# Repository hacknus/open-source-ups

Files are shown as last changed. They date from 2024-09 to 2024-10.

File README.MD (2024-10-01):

# Open Source UPS
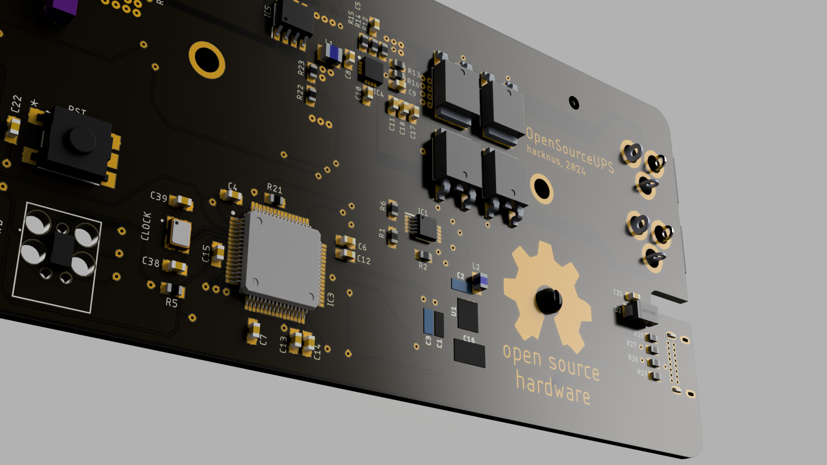
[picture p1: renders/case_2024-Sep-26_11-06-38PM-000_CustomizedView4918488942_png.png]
pcb view


UPS are commonly used in server applications to protect against power outages. For home applications, for example to protect a NAS, small Uninterruptible Power Supplies (UPS) do exist, but they all lack the USB HID communication to shut down the NAS/Server/Host when the battery gets low.
For small scale applications like Synology NAS products that operate at 12V, there currently exists no UPS product that is able to buffer the power and communicate over USB when the battery level gets critically low.
Only high voltage solutions (110V or 230V) exist, which also include an inverter and are thus much less efficient and overpowered for a simple 12V Synology NAS.
This is a simple, open source UPS, based around an STM32F405 and written in Rust.

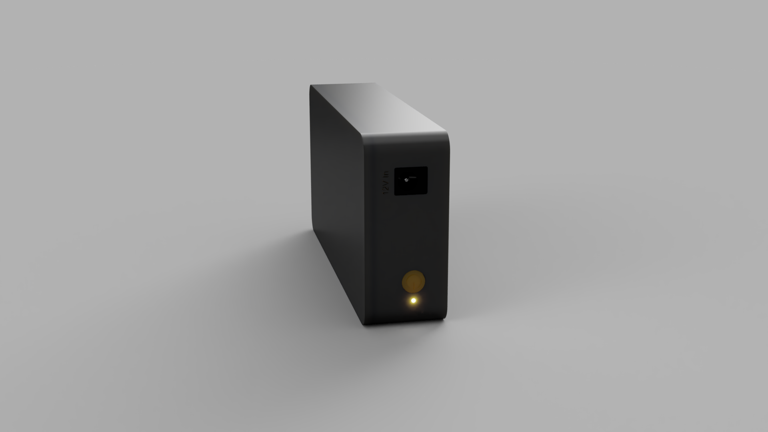
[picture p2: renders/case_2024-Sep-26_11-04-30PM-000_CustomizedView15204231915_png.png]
front view

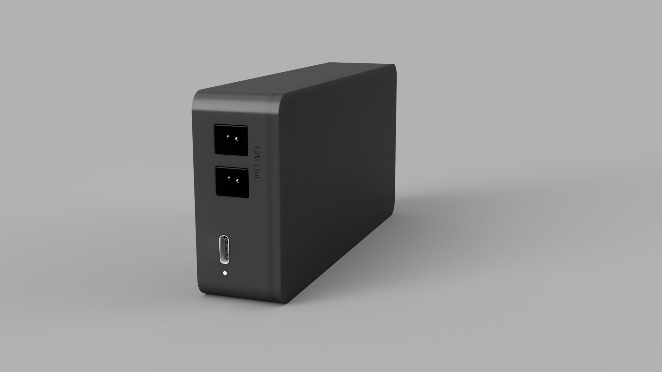
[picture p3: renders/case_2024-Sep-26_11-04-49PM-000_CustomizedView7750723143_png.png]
back view

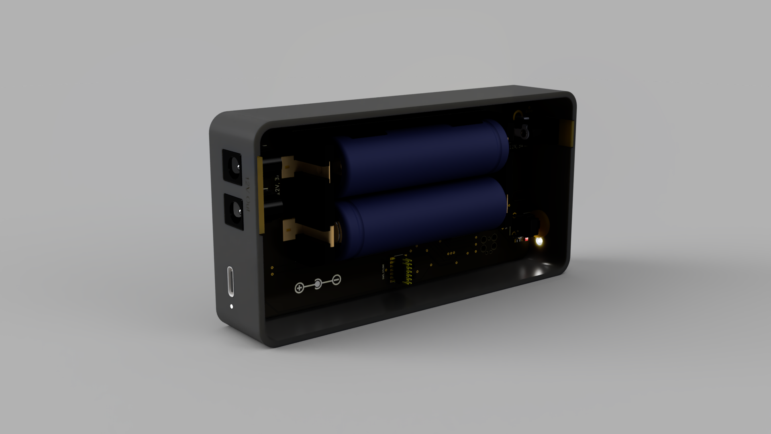
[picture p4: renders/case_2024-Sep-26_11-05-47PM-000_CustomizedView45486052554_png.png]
inside view


The USB HID communication is based on the great work done by [abratchik](https://github.com/abratchik) for the Arduino platform [here](https://github.com/abratchik/HIDPowerDevice/tree/master). 
The hardware is essentially just a charging circuit where the remaining capacity is monitored by the MCU.

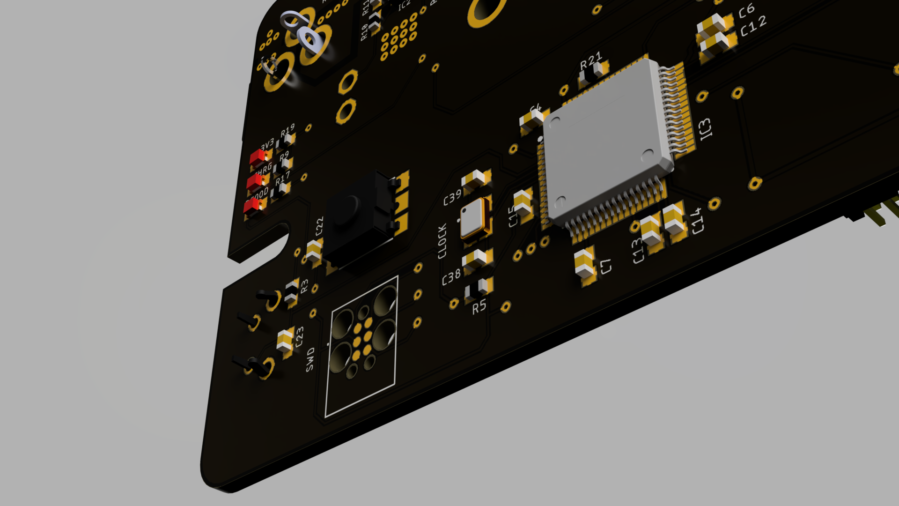
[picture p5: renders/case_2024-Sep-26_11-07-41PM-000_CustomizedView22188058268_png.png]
pcb view


## Hardware
Attention! This pcb does not contain a battery protection circuit - if you wish to implement one, just use the Keystone 1047 battery case instead of the Keystone 1048P and wire a breakout 2S BMS before connecting the batteries to the PCB.
The hardware can be found in the [hardware folder](hardware), containing step files for the case as well as EAGLE files for the PCB.

## Flashing the firmware
Connect the board using a ST-Link V3 (with TagConnect) to a USB port on the computer. Be sure to power the board with an
additional USB-C connector. (ST-Link does not provide power)  
First start the openocd server in a terminal/console window:
```openocd -f interface/stlink-v2-1.cfg -f target/stm32f4x.cfg```   
Flash/Run the code on the hardware using:  
```cargo run --release```  
note: release is important for USB to work reliably!

To set up your system, be sure to
follow [this guide](https://docs.rust-embedded.org/discovery/f3discovery/03-setup/index.html)!

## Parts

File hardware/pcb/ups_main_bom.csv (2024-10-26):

Qty | Value | Device | Package | Parts | Description | ARROW_PART_NUMBER | ARROW_PRICE-STOCK | AVAILABILITY | BUILT_BY | CONFIGURATION__POLE-THROW_ | COPYRIGHT | DESCRIPTION | HEIGHT | MANUFACTURER_NAME | MANUFACTURER_PART_NUMBER | MAX_SWITCHING_CURRENT | MAX_SWITCHING_VOLTAGE_AC_ | MF | MOUSER_PART_NUMBER | MOUSER_PRICE-STOCK | MP | PACKAGE | POPULARITY | PRICE | PRODUCT_TYPE | PROD_ID | PURCHASE-URL | RS_PART_NUMBER | RS_PRICE-STOCK | SPICEPREFIX | SWITCH_TYPE | TE_PART_NUMBER | TP_SIGNAL_NAME | VALUE | VENDOR
5 |  | LEDCHIPLED_0805 | CHIPLED_0805 | 3V3, CHRG, FLT, PGOOD, STAT | LED
1 | 0.1uF | 0.1UF-0603-25V-5% | 603 | C2 | 0.1µF ceramic capacitors |  |  |  |  |  |  |  |  |  |  |  |  |  |  |  |  |  |  |  |  | CAP-08604 |  |  |  |  |  |  |  | 0.1uF
9 | 0.1uF | C-EUC0603K | C0603K | C4, C6, C7, C14, C15, C19, C20, C22, C23 | CAPACITOR, European symbol |  |  |  |  |  |  |  |  |  |  |  |  |  |  |  |  |  | 30 |  |  |  |  |  |  | C
1 | 1-1571636-0 | 1-1571636-0 | SW5_1571636 | RST |  |  |  |  | EMA_UL_Team | Single Pole - Single Throw | Copyright (C) 2016 Accelerated Designs. All rights reserved | TACT,SMT,GULL WING,260GF,T&R |  |  | 1-1571636-0 | - | - |  |  |  |  |  |  |  | Switch |  |  |  |  |  | Tactile Switches | 1-1571636-0 |  |  | TE Connectivity
1 | 1.21k | R-EU_R0603 | R0603 | R11 | RESISTOR, European symbol |  |  |  |  |  |  |  |  |  |  |  |  |  |  |  |  |  | 70 |  |  |  |  |  |  | R
1 | 1.54M | R-EU_R0603 | R0603 | R7 | RESISTOR, European symbol |  |  |  |  |  |  |  |  |  |  |  |  |  |  |  |  |  | 70 |  |  |  |  |  |  | R
1 | 1.5uF | C-EUC0603K | C0603K | C9 | CAPACITOR, European symbol |  |  |  |  |  |  |  |  |  |  |  |  |  |  |  |  |  | 30 |  |  |  |  |  |  | C
1 | 1000pF | C-EUC0603K | C0603K | C5 | CAPACITOR, European symbol |  |  |  |  |  |  |  |  |  |  |  |  |  |  |  |  |  | 30 |  |  |  |  |  |  | C
1 | 100nF | C-EUC0603K | C0603K | C8 | CAPACITOR, European symbol |  |  |  |  |  |  |  |  |  |  |  |  |  |  |  |  |  | 30 |  |  |  |  |  |  | C
1 | 1048P | 1048P | 1048P | U2 | KEYSTONE - 1048P - BATTERY HOLDER, 18650, SMD |  |  |  |  |  |  | KEYSTONE - 1048P - BATTERY HOLDER, 18650, SMD | mm | Keystone Electronics | 1048P |  |  |  | 534-1048P | https://www.mouser.co.uk/ProductDetail/Keystone-Electronics/1048P?qs=9%252Bwcgl%2FJqd1h8Vx3IFpTxA%3D%3D
4 | 10k | R-EU_R0603 | R0603 | R3, R5, R10, R21 | RESISTOR, European symbol |  |  |  |  |  |  |  |  |  |  |  |  |  |  |  |  |  | 70 |  |  |  |  |  |  | R
1 | 10uF | 10UF-1210-50V-20% | 1210 | C16 | 10.0µF ceramic capacitors |  |  |  |  |  |  |  |  |  |  |  |  |  |  |  |  |  |  |  |  | CAP-09824 |  |  |  |  |  |  |  | 10uF
4 | 10uF | C-EUC0603K | C0603K | C12, C13, C17, C18 | CAPACITOR, European symbol |  |  |  |  |  |  |  |  |  |  |  |  |  |  |  |  |  | 30 |  |  |  |  |  |  | C
1 | 158k | R-EU_R0603 | R0603 | R2 | RESISTOR, European symbol |  |  |  |  |  |  |  |  |  |  |  |  |  |  |  |  |  | 70 |  |  |  |  |  |  | R
1 | 18k | R-EU_R0603 | R0603 | R15 | RESISTOR, European symbol |  |  |  |  |  |  |  |  |  |  |  |  |  |  |  |  |  | 70 |  |  |  |  |  |  | R
5 | 1k | R-EU_R0603 | R0603 | R9, R17, R18, R19, R31 | RESISTOR, European symbol |  |  |  |  |  |  |  |  |  |  |  |  |  |  |  |  |  | 70 |  |  |  |  |  |  | R
3 | 1uF | C-EUC0603K | C0603K | C11, C21, C25 | CAPACITOR, European symbol |  |  |  |  |  |  |  |  |  |  |  |  |  |  |  |  |  | 30 |  |  |  |  |  |  | C
1 | 2.2uF | C-EUC0603K | C0603K | C10 | CAPACITOR, European symbol |  |  |  |  |  |  |  |  |  |  |  |  |  |  |  |  |  | 30 |  |  |  |  |  |  | C
1 | 200k | R-EU_R0603 | R0603 | R6 | RESISTOR, European symbol |  |  |  |  |  |  |  |  |  |  |  |  |  |  |  |  |  | 70 |  |  |  |  |  |  | R
3 | 20k | R-EU_R0603 | R0603 | R1, R13, R16 | RESISTOR, European symbol |  |  |  |  |  |  |  |  |  |  |  |  |  |  |  |  |  | 70 |  |  |  |  |  |  | R
2 | 22 | R-EU_R0603 | R0603 | R26, R27 | RESISTOR, European symbol |  |  |  |  |  |  |  |  |  |  |  |  |  |  |  |  |  | 70 |  |  |  |  |  |  | R
2 | 22pF | C-EUC0603K | C0603K | C38, C39 | CAPACITOR, European symbol |  |  |  |  |  |  |  |  |  |  |  |  |  |  |  |  |  | 30 |  |  |  |  |  |  | C
2 | 22uF | 22UF-0603-6.3V-20% | 603 | C1, C3 | 22µF ceramic capacitors |  |  |  |  |  |  |  |  |  |  |  |  |  |  |  |  |  |  |  |  | CAP-14464 |  |  |  |  |  |  |  | 22uF
1 | 22uF | C-EUC0603K | C0603K | C26 | CAPACITOR, European symbol |  |  |  |  |  |  |  |  |  |  |  |  |  |  |  |  |  | 30 |  |  |  |  |  |  | C
1 | 249k | R-EU_R0603 | R0603 | R8 | RESISTOR, European symbol |  |  |  |  |  |  |  |  |  |  |  |  |  |  |  |  |  | 70 |  |  |  |  |  |  | R
2 | 27k | R-EU_R0603 | R0603 | R22, R25 | RESISTOR, European symbol |  |  |  |  |  |  |  |  |  |  |  |  |  |  |  |  |  | 70 |  |  |  |  |  |  | R
1 | 280k | R-EU_R0603 | R0603 | R12 | RESISTOR, European symbol |  |  |  |  |  |  |  |  |  |  |  |  |  |  |  |  |  | 70 |  |  |  |  |  |  | R
2 | 4k7 | R-EU_R0603 | R0603 | R28, R29 | RESISTOR, European symbol |  |  |  |  |  |  |  |  |  |  |  |  |  |  |  |  |  | 70 |  |  |  |  |  |  | R
2 | 68k | R-EU_R0603 | R0603 | R23, R24 | RESISTOR, European symbol |  |  |  |  |  |  |  |  |  |  |  |  |  |  |  |  |  | 70 |  |  |  |  |  |  | R
3 | 694106301002 | 694106301002 | 694106301002_1 | J1, J2, J3 | WURTH ELEKTRONIK - 694106301002 - CONNECTOR, POWER ENTRY, JACK, 3A, 20VDC |  |  |  |  |  |  | WURTH ELEKTRONIK - 694106301002 - CONNECTOR, POWER ENTRY, JACK, 3A, 20VDC | mm | Wurth Elektronik | 694106301002 |  |  |  | 710-694106301002 | https://www.mouser.co.uk/ProductDetail/Wurth-Elektronik/694106301002?qs=a9WhcLg8qCwOEkcI62k5mA%3D%3D
1 | 80.6k | R-EU_R0603 | R0603 | R14 | RESISTOR, European symbol |  |  |  |  |  |  |  |  |  |  |  |  |  |  |  |  |  | 70 |  |  |  |  |  |  | R
1 | 8MHz | ABM8AIG-8.000MHZ-1Z-T | ABM8AIG8000MHZ1ZT | CLOCK | Crystals 18pF 8MHz 10ppm AEC-Q200 -40C +125C |  |  |  |  |  |  | Crystals 18pF 8MHz 10ppm AEC-Q200 -40C +125C | 0.8mm | ABRACON | ABM8AIG-8.000MHZ-1Z-T |  |  |  | 815-M8AIG-8-1ZT | https://www.mouser.com/Search/Refine.aspx?Keyword=815-M8AIG-8-1ZT
1 | AP63203 | AP63203 | SOT23-6 | U1 | Diodes Inc. AP63203 3.8V-32V input 3.3V Buck |  |  |  |  |  |  |  |  |  |  |  |  |  |  |  |  |  |  |  |  | VREG-15244 |  |  |  |  |  |  |  | AP63203
1 | FSMRACDAH | FSMRACDAH | FSMRACDAH | SW | TE CONNECTIVITY / ALCOSWITCH - FSMRACDAH - TACTILE SWITCH, SPST-NO, 0.05A, 24V, TH |  |  |  |  |  |  | TE CONNECTIVITY / ALCOSWITCH - FSMRACDAH - TACTILE SWITCH, SPST-NO, 0.05A, 24V, TH | 9.2mm | TE Connectivity | FSMRACDAH |  |  |  | 506-FSMRACDAH | https://www.mouser.co.uk/ProductDetail/TE-Connectivity-Alcoswitch/FSMRACDAH?qs=GXuM9q1TrDlqFSLkwG2zzQ%3D%3D
1 | FTSH-107-01-L-DV-K | FTSH-107-01-L-DV-K | FTSH-107-XX-YYY-DV-K | SWD_STLINK | 14 Position, High Reliability Header Strips, 0.050 pitch" | FTSH-107-01-L-DV-K | https://www.arrow.com/en/products/ftsh-107-01-l-dv-k/samtec |  |  |  |  | 14 Position, High Reliability Header Strips, 0.050&quot | pitch | mm | SAMTEC | FTSH-107-01-L-DV-K |  |  |  | 200-FTSH10701LDVK | https://www.mouser.co.uk/ProductDetail/Samtec/FTSH-107-01-L-DV-K?qs=%252BZP6%2F%252BtExtBNGLAeWROTVA%3D%3D
4 | IPD068P03L3GATMA1 | IPD068P03L3GATMA1 | IPD068P03L3GATMA1 | Q1, Q2, Q3, Q4 | MOSFET TRENCH |  |  |  |  |  |  | MOSFET TRENCH <= 40V | 2.41mm | Infineon | IPD068P03L3GATMA1 |  |  |  | 726-IPD068P03L3GATMA | https://www.mouser.co.uk/ProductDetail/Infineon-Technologies/IPD068P03L3GATMA1?qs=RJIhqtkBntMB6UQHOyDZmg%3D%3D
1 | LTC4079EDD#TRPBF | LTC4079EDD#TRPBF | SON50P300X300X80-11N | IC2 | Battery Management Low Iq 60V, 250mA Linear Charger |  |  |  |  |  |  | Battery Management Low Iq 60V, 250mA Linear Charger | 0.8mm | Analog Devices | LTC4079EDD#TRPBF |  |  |  | 584-LTC4079EDD#TRPBF | https://www.mouser.co.uk/ProductDetail/Analog-Devices/LTC4079EDDTRPBF?qs=hVkxg5c3xu9bytIIUSwPNA%3D%3D
1 | LTC4416EMS-1#PBF | LTC4416EMS-1#PBF | SOP50P490X110-10N | IC1 | Linear Technology LTC4416EMS-1#PBF, MOSFET Controller 10-Pin, MSOP |  |  |  |  |  |  | Linear Technology LTC4416EMS-1#PBF, MOSFET Controller 10-Pin, MSOP | 1.1mm | Analog Devices | LTC4416EMS-1#PBF |  |  |  | 584-LTC4416EMS-1#PBF | https://www.mouser.co.uk/ProductDetail/Analog-Devices/LTC4416EMS-1PBF?qs=hVkxg5c3xu9mDay6QbsUoQ%3D%3D
1 | MCS1802GS-20-Z | MCS1802GS-20-Z | SOIC127P600X175-8N | IC5 | Board Mount Current Sensors 3.3V Hall current sensor. 1.5% accuracy. 2.4kV Isolation |  |  |  |  |  |  | Board Mount Current Sensors 3.3V Hall current sensor. 1.5% accuracy. 2.4kV Isolation | 1.75mm | Monolithic Power Systems (MPS) | MCS1802GS-20-Z |  |  |  | 946-MCS1802GS-20-Z | https://www.mouser.co.uk/ProductDetail/Monolithic-Power-Systems-MPS/MCS1802GS-20-Z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
1 | MLZ2012M4R7HT000 | MLZ2012M4R7HT000 | INDC2012X145N | L2 | Inductor Power Shielded Multi-Layer 4.7uH 20% 2MHz Ferrite 0.4A 0.442Ohm DCR 0805 T/R |  |  |  |  |  |  | Inductor Power Shielded Multi-Layer 4.7uH 20% 2MHz Ferrite 0.4A 0.442Ohm DCR 0805 T/R | 1.45mm | TDK-Lambda | MLZ2012M4R7HT000 |  |  |  | 810-MLZ2012M4R7HT000 | https://www.mouser.co.uk/ProductDetail/TDK/MLZ2012M4R7HT000?qs=%2FPzWLGNeQ%252BgQgMrI9kQ17A%3D%3D
1 | SRP2512-1R0M | SRP2512-1R0M | INDC2520X120N | L1 | BOURNS - SRP2512-1R0M - INDUCTOR, WIREWOUND, 1UH, 20%, 3.1A |  |  |  |  |  |  | BOURNS - SRP2512-1R0M - INDUCTOR, WIREWOUND, 1UH, 20%, 3.1A | 1.2mm | Bourns | SRP2512-1R0M |  |  |  | 652-SRP2512-1R0M | https://www.mouser.co.uk/ProductDetail/Bourns/SRP2512-1R0M?qs=fHAk5VQYflc1VrtfzBcSKQ%3D%3D
1 | SS12 | SS12 | DO214AC | D2 | http://octopart.com/ss12-tp-mcc-9293796 |  |  | Unavailable |  |  |  | SS12 Series 500 mV 1 A 20 V Max Reverse Voltage Schottky Rectifier - DO-214AC |  |  |  |  |  | Klein Tools, |  |  | SS12 | DO-214AC-214 ON Semiconductor |  | None
1 | STM32F405RGT6 | STM32F405RGT6 | QFP50P1200X1200X160-64N | IC3 | MCU 32-Bit, ARM Cortex M4, 1MB Flash STMicroelectronics STM32F405RGT6, 32bit ARM Cortex M4F Microcontroller, 168MHz, 1024 kB Flash, 64-Pin LQFP |  |  |  |  |  |  | MCU 32-Bit, ARM Cortex M4, 1MB Flash STMicroelectronics STM32F405RGT6, 32bit ARM Cortex M4F Microcontroller, 168MHz, 1024 kB Flash, 64-Pin LQFP | 1.6mm | STMicroelectronics | STM32F405RGT6 |  |  |  | 511-STM32F405RGT6 | https://www.mouser.co.uk/ProductDetail/STMicroelectronics/STM32F405RGT6?qs=Z8%252BeY1k3TIKgj7QWsYGpQw%3D%3D
1 | T491D226M035AT | T491D226M035AT | T491D | C24 | T491, Tantalum, MnO2 Tantalum, Commercial Grade, 22 uF, 20%, 35 VDC, 125C, -55C, 85C, SMD, MnO2, Molded, 6 % , 700 mOhms, 7700 nA, 446.84 mg, 7343, 2.8mm, Height Max = 3.1mm, 500, 156 Weeks |  |  |  |  |  |  | T491, Tantalum, MnO2 Tantalum, Commercial Grade, 22 uF, 20%, 35 VDC, 125C, -55C, 85C, SMD, MnO2, Molded, 6 % , 700 mOhms, 7700 nA, 446.84 mg, 7343, 2.8mm, Height Max = 3.1mm, 500, 156 Weeks | 3.1mm | KEMET | T491D226M035AT |  |  |  | 80-T491D226M035 | https://www.mouser.co.uk/ProductDetail/KEMET/T491D226M035AT?qs=2Dzs5xnho3a9L55s8fyD1A%3D%3D
1 | TC2030-IDC | TC2030-IDC | TC2030IDC | SWD | CABLE ADAPTER 6 POS |  |  |  |  |  |  | CABLE ADAPTER 6 POS | 19mm | Tag Connect | TC2030-IDC
2 | TPPAD1-17 | TPPAD1-17 | P1-17 | NTC+, NTC- | Test pad |  |  |  |  |  |  |  |  |  |  |  |  |  |  |  |  |  | 0
1 | TPS613782QWRTERQ1 | TPS613783QWRTERQ1 | QFN50P300X300X80-17N | IC4 | Switching Voltage Regulators 18.5-V output, 4.8-A synchronous boost converter with load disconnect 16-WQFN -40 to 125 |  |  |  |  |  |  | Switching Voltage Regulators 18.5-V output, 4.8-A synchronous boost converter with load disconnect 16-WQFN -40 to 125 | 0.8mm | Texas Instruments | TPS613783QWRTERQ1 |  |  |  | 595-PS613783QWRTERQ1 | https://www.mouser.co.uk/ProductDetail/Texas-Instruments/TPS613783QWRTERQ1?qs=DRkmTr78QAS2n8buuGBazA%3D%3D
1 | USB4085-GF-A_REVA4 | USB4085-GF-A_REVA4 | GCT_USB4085-GF-A_REVA4 | USB | USB 2.0 Type C Receptacle Dip Type, PCB Top Mount Check prices |  |  | In Stock |  |  |  | USB-C (USB TYPE-C) USB 2.0 Receptacle Connector 24 (16+8 Dummy) Position Through Hole, Right Angle, low cost, 3.46mm profile, 16 pin, horizontal, Top mount |  |  |  |  |  | Global Connector Technology |  |  | USB4085-GF-A | None |  | None |  |  | https://pricing.snapeda.com/search/part/USB4085-GF-A/?ref=eda

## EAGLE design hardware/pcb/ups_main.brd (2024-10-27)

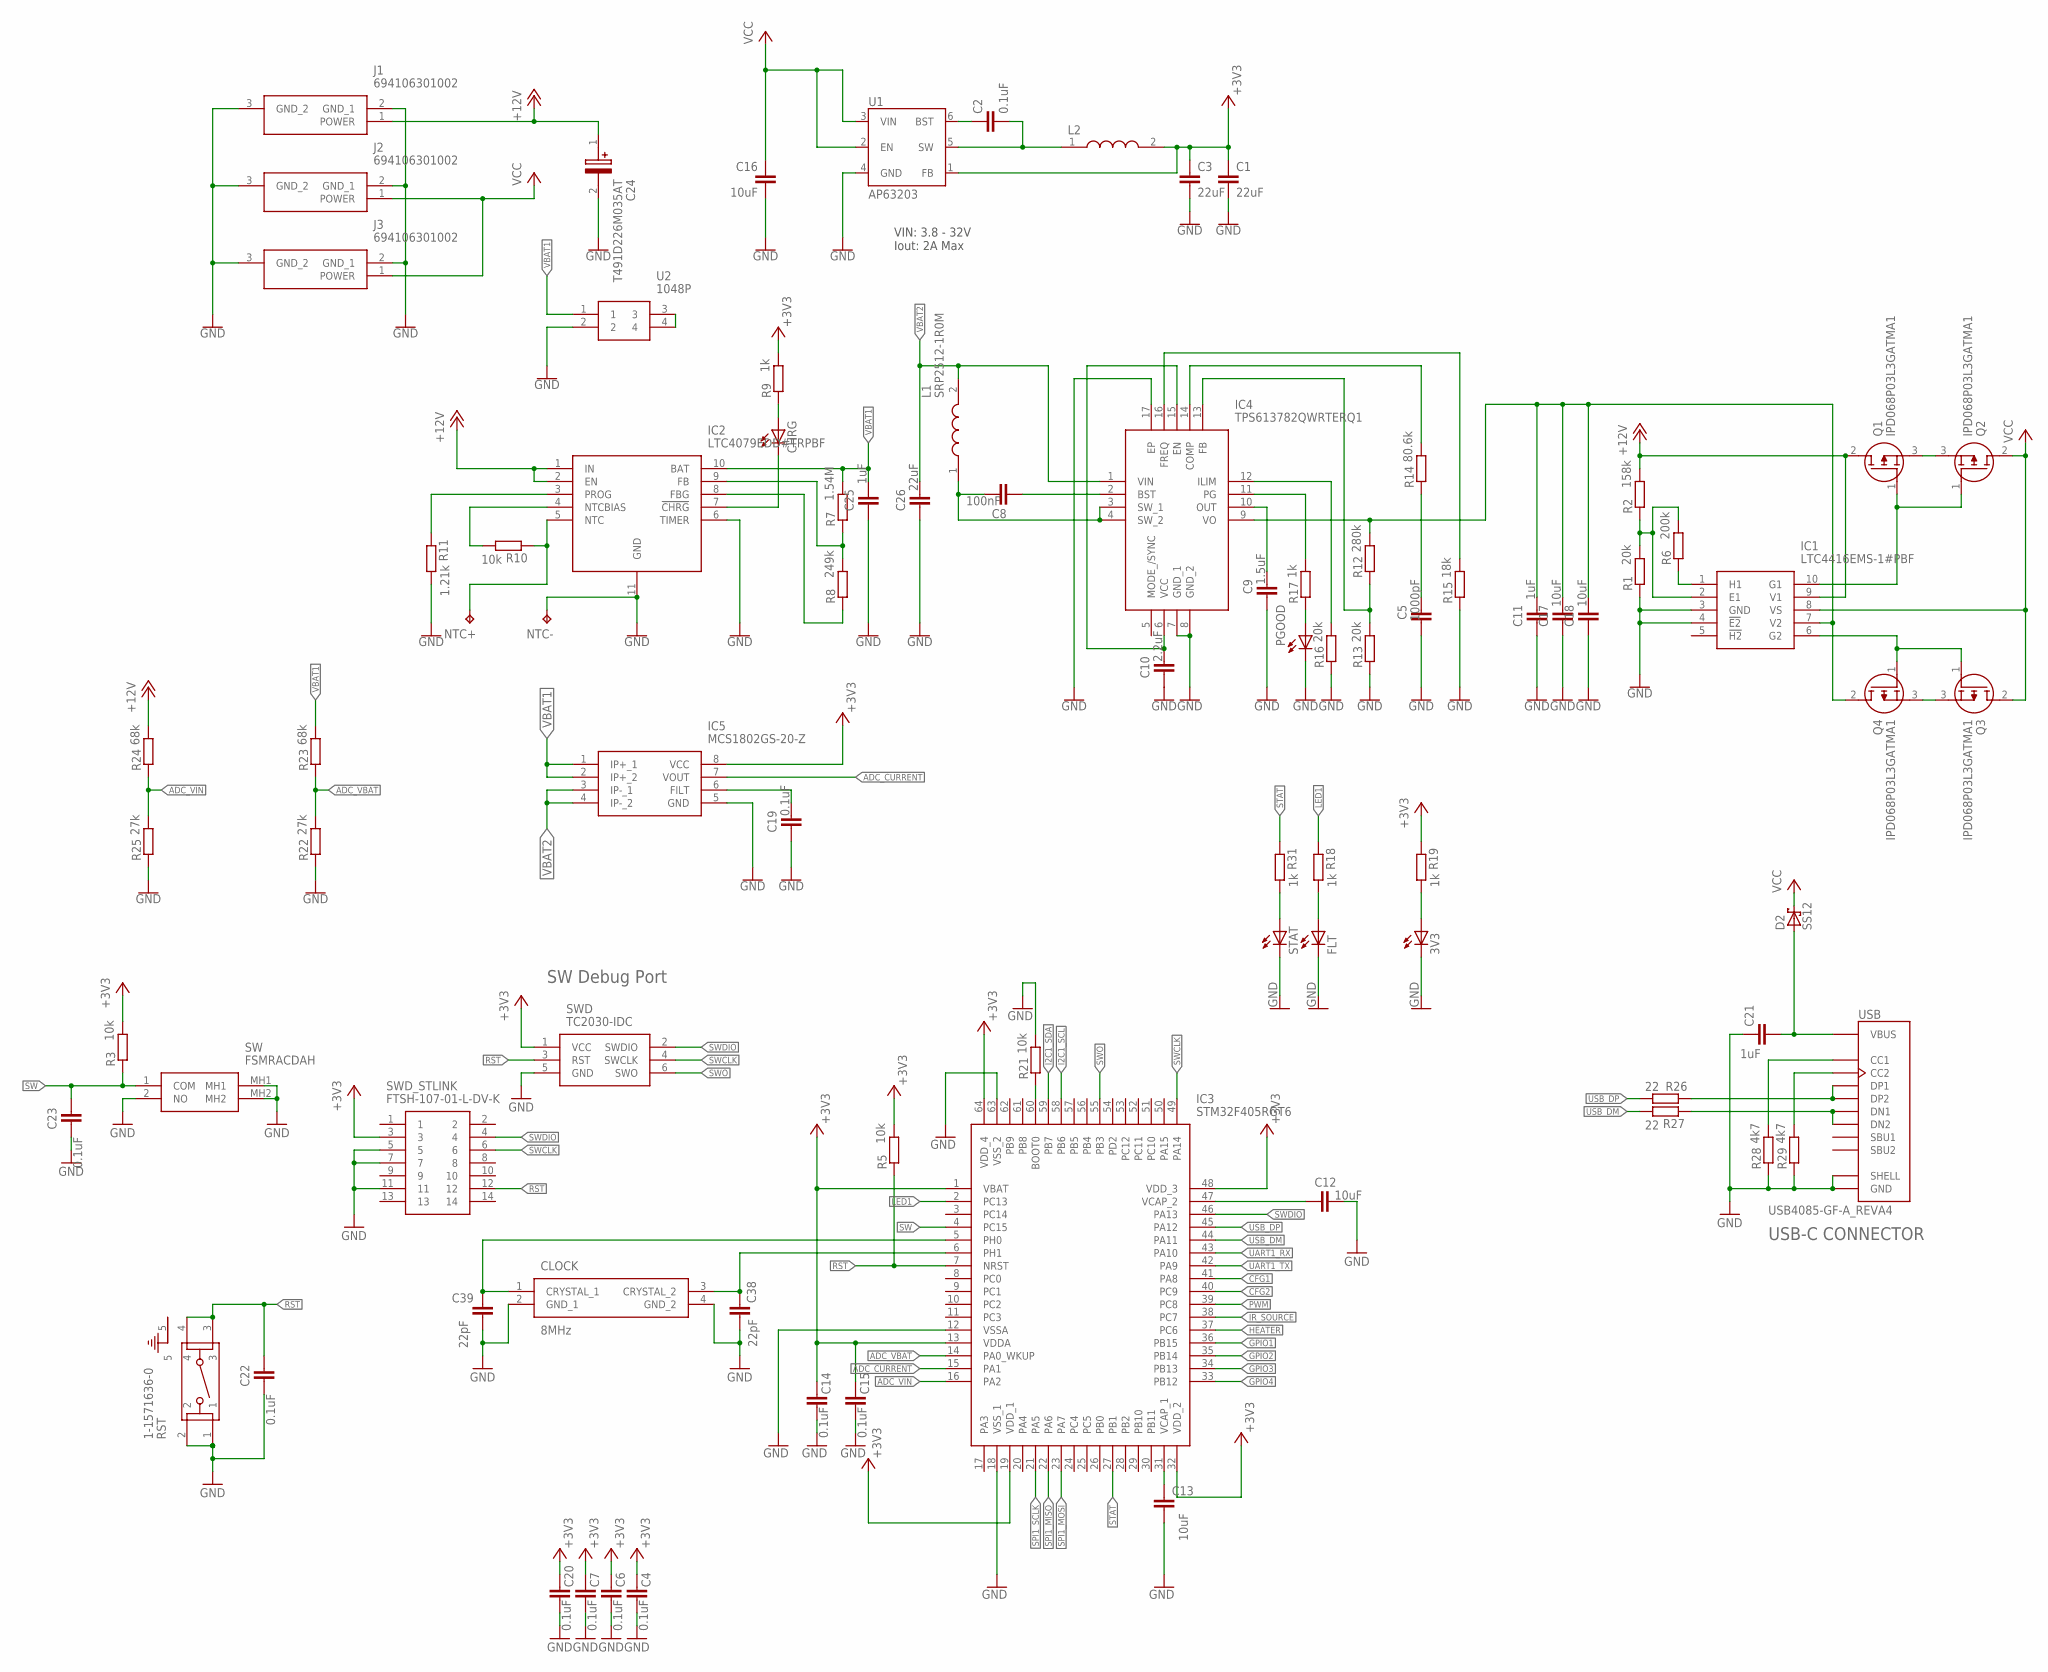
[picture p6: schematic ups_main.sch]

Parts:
3V3: LEDCHIPLED_0805; CHIPLED_0805
C1, C3: 22uF; 0603
C2: 0.1uF; 0603
C4, C6, C7, C14, C15, C19, C20, C22, C23: 0.1uF; C0603K
C5: 1000pF; C0603K
C8: 100nF; C0603K
C9: 1.5uF; C0603K
C10: 2.2uF; C0603K
C11, C21, C25: 1uF; C0603K
C12, C13, C17, C18: 10uF; C0603K
C16: 10uF; 1210
C24: T491D226M035AT; T491D
C26: 22uF; C0603K
C38, C39: 22pF; C0603K
CHRG: LEDCHIPLED_0805; CHIPLED_0805
CLOCK: 8MHz; ABM8AIG8000MHZ1ZT
D2: SS12; DO214AC
FLT: LEDCHIPLED_0805; CHIPLED_0805
IC1: LTC4416EMS-1#PBF; SOP50P490X110-10N
IC2: LTC4079EDD#TRPBF; SON50P300X300X80-11N
IC3: STM32F405RGT6; QFP50P1200X1200X160-64N
IC4: TPS613782QWRTERQ1; QFN50P300X300X80-17N
IC5: MCS1802GS-20-Z; SOIC127P600X175-8N
J1, J2, J3: 694106301002; 694106301002_1
L1: SRP2512-1R0M; INDC2520X120N
L2: MLZ2012M4R7HT000; INDC2012X145N
NTC+: TPPAD1-17; P1-17
NTC-: TPPAD1-17; P1-17
PGOOD: LEDCHIPLED_0805; CHIPLED_0805
Q1, Q2, Q3, Q4: IPD068P03L3GATMA1
R1, R13, R16: 20k; R0603
R2: 158k; R0603
R3, R5, R10, R21: 10k; R0603
R6: 200k; R0603
R7: 1.54M; R0603
R8: 249k; R0603
R9, R17, R18, R19, R31: 1k; R0603
R11: 1.21k; R0603
R12: 280k; R0603
R14: 80.6k; R0603
R15: 18k; R0603
R22, R25: 27k; R0603
R23, R24: 68k; R0603
R26, R27: 22; R0603
R28, R29: 4k7; R0603
RST: 1-1571636-0; SW5_1571636
STAT: LEDCHIPLED_0805; CHIPLED_0805
SW: FSMRACDAH
SWD: TC2030-IDC; TC2030IDC
SWD_STLINK: FTSH-107-01-L-DV-K; FTSH-107-XX-YYY-DV-K
U1: AP63203; SOT23-6
U2: 1048P
USB: USB4085-GF-A_REVA4; GCT_USB4085-GF-A_REVA4

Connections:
+3V3: C1.1, C3.1, C4.1, C6.1, C7.1, C14.1, C15.1, C20.1, IC3.1 (VBAT), IC3.13 (VDDA), IC3.19 (VDD_1), IC3.32 (VDD_2), IC3.48 (VDD_3), IC3.64 (VDD_4), IC5.8 (VCC), L2.2, R3.2, R5.2, R9.2, R19.1, SWD.1 (VCC), SWD_STLINK.3, U1.1 (FB)
+12V: C24.1 (+), IC1.9 (V1), IC2.1 (IN), IC2.2 (EN), J1.1 (POWER), Q1.2 (D), R2.2, R24.2
ADC_CURRENT: IC3.15 (PA1), IC5.7 (VOUT)
ADC_VBAT: IC3.14 (PA0_WKUP), R22.2, R23.1
ADC_VIN: IC3.16 (PA2), R24.1, R25.2
CFG1: IC3.41 (PA8)
CFG2: IC3.40 (PC9)
GND: 3V3.C, C1.2, C3.2, C4.2, C5.1, C6.2, C7.2, C9.1, C10.1, C11.1, C12.2, C13.2, C14.2, C15.2, C16.2, C17.1, C18.1, C19.1, C20.2, C21.1, C22.2, C23.2, C24.2 (-), C25.1, C26.1, C38.2, C39.2, CLOCK.2 (GND_1), CLOCK.4 (GND_2), FLT.C, IC1.3 (GND), IC1.4 (!E2), IC2.6 (TIMER), IC2.11 (GND), IC3.12 (VSSA), IC3.18 (VSS_1), IC3.63 (VSS_2), IC4.7 (GND_1), IC4.8 (GND_2), IC4.17 (EP), IC5.5 (GND), J1.2 (GND_1), J1.3 (GND_2), J2.2 (GND_1), J2.3 (GND_2), J3.2 (GND_1), J3.3 (GND_2), NTC-.TP, PGOOD.C, R1.1, R11.2, R13.1, R15.1, R16.1, R21.2, R22.1, R25.1, R28.1, R29.1, RST.1, RST.2, STAT.C, SW.2 (NO), SW.MH1, SW.MH2, SWD.5 (GND), SWD_STLINK.5, SWD_STLINK.7, SWD_STLINK.11, U1.4 (GND), U2.2, USB.A1 (GND), USB.A12 (GND), USB.B1 (GND), USB.B12 (GND), USB.P1 (SHELL), USB.P2 (SHELL), USB.P3 (SHELL), USB.P4 (SHELL)
GPIO1: IC3.36 (PB15)
GPIO2: IC3.35 (PB14)
GPIO3: IC3.34 (PB13)
GPIO4: IC3.33 (PB12)
HEATER: IC3.37 (PC6)
I2C1_SCL: IC3.58 (PB6)
I2C1_SDA: IC3.59 (PB7)
IR_SOURCE: IC3.38 (PC7)
LED1: IC3.2 (PC13), R18.1
unnamed: C2.1, U1.6 (BST)
unnamed: Q3.3 (S), Q4.3 (S)
unnamed: IC1.6 (G2), Q3.1 (G), Q4.1 (G)
unnamed: FLT.A, R18.2
unnamed: IC1.10 (G1), Q1.1 (G), Q2.1 (G)
unnamed: C12.1, IC3.47 (VCAP_2)
unnamed: IC1.1 (H1), R6.1
unnamed: IC1.2 (E1), R1.2, R2.1, R6.2
unnamed: C2.2, L2.1, U1.5 (SW)
unnamed: Q1.3 (S), Q2.3 (S)
unnamed: IC4.12 (ILIM), R16.2
unnamed: C13.1, IC3.31 (VCAP_1)
unnamed: IC4.11 (PG), R17.2
unnamed: IC2.4 (NTCBIAS), R10.2
unnamed: IC2.5 (NTC), NTC+.TP, R10.1
unnamed: IC2.3 (PROG), R11.1
unnamed: IC2.9 (FB), R7.1, R8.2
unnamed: IC2.8 (FBG), R8.1
unnamed: CHRG.C, IC2.7 (!CHRG)
unnamed: C38.1, CLOCK.3 (CRYSTAL_2), IC3.6 (PH1)
unnamed: C9.2, IC4.10 (OUT)
unnamed: IC4.16 (FREQ), R15.2
unnamed: IC4.14 (COMP), R14.2
unnamed: C8.1, IC4.2 (BST)
unnamed: C8.2, IC4.3 (SW_1), IC4.4 (SW_2), L1.1
unnamed: C39.1, CLOCK.1 (CRYSTAL_1), IC3.5 (PH0)
unnamed: C5.2, R14.1
unnamed: IC4.13 (FB), R12.1, R13.2
unnamed: 3V3.A, R19.2
unnamed: R31.2, STAT.A
unnamed: C21.2, D2.A, USB.A4 (VBUS), USB.A9 (VBUS), USB.B4 (VBUS), USB.B9 (VBUS)
unnamed: PGOOD.A, R17.1
unnamed: CHRG.A, R9.1
unnamed: IC3.60 (BOOT0), R21.1
unnamed: R26.1, USB.A6 (DP1), USB.B6 (DP2)
unnamed: C10.2, IC4.6 (VCC), IC4.15 (EN)
unnamed: R27.1, USB.A7 (DN1), USB.B7 (DN2)
unnamed: C19.2, IC5.6 (FILT)
unnamed: U2.3, U2.4
unnamed: R29.2, USB.B5 (CC2)
unnamed: R28.2, USB.A5 (CC1)
PWM: IC3.39 (PC8)
RST: C22.1, IC3.7 (NRST), R5.1, RST.3, RST.4, SWD.3 (RST), SWD_STLINK.12
SPI1_MISO: IC3.22 (PA6)
SPI1_MOSI: IC3.23 (PA7)
SPI1_SCLK: IC3.21 (PA5)
STAT: IC3.27 (PB1), R31.1
SW: C23.1, IC3.4 (PC15), R3.1, SW.1 (COM)
SWCLK: IC3.49 (PA14), SWD.4 (SWCLK), SWD_STLINK.6
SWDIO: IC3.46 (PA13), SWD.2 (SWDIO), SWD_STLINK.4
SWO: IC3.55 (PB3), SWD.6 (SWO)
UART1_RX: IC3.43 (PA10)
UART1_TX: IC3.42 (PA9)
USB_DM: IC3.44 (PA11), R27.2
USB_DP: IC3.45 (PA12), R26.2
VBAT1: C25.2, IC2.10 (BAT), IC5.1 (IP+_1), IC5.2 (IP+_2), R7.2, R23.2, U2.1
VBAT2: C26.2, IC4.1 (VIN), IC5.3 (IP-_1), IC5.4 (IP-_2), L1.2
VCC: C16.1, D2.C, IC1.8 (VS), J2.1 (POWER), J3.1 (POWER), Q2.2 (D), Q3.2 (D), U1.2 (EN), U1.3 (VIN)
VO: C11.2, C17.2, C18.2, IC1.7 (V2), IC4.9 (VO), Q4.2 (D), R12.2

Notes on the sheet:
SW Debug Port
VIN: 3.8 - 32V Iout: 2A Max
USB-C CONNECTOR

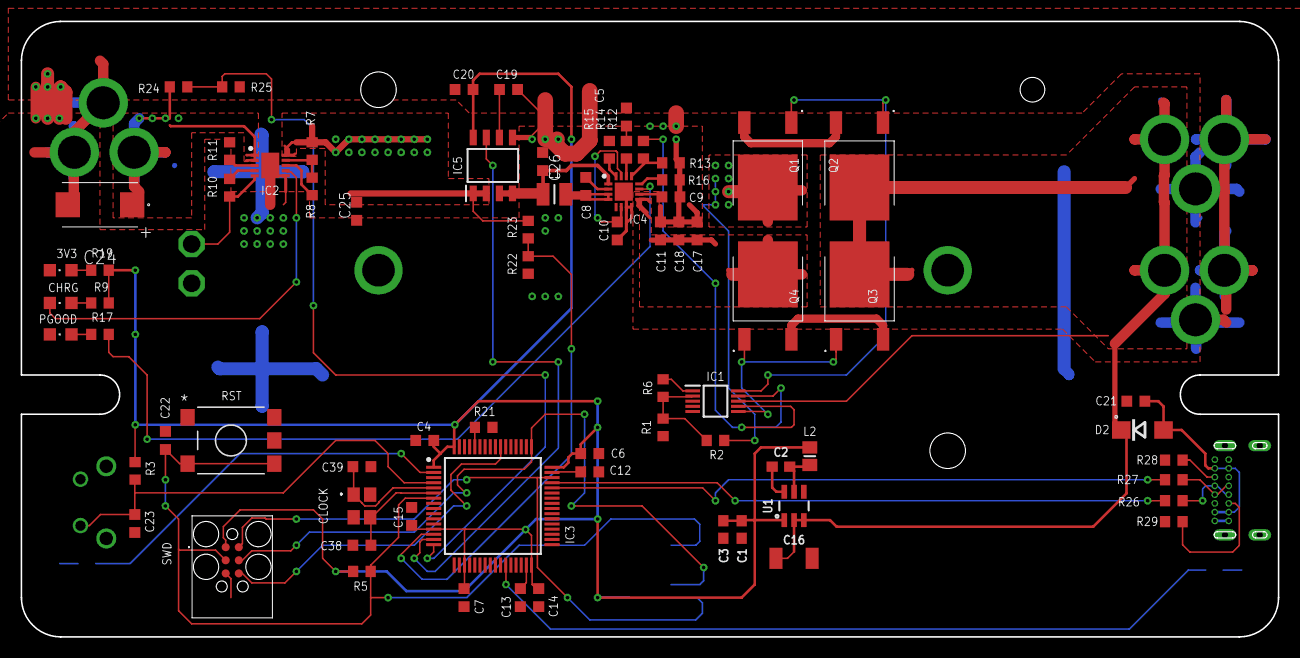
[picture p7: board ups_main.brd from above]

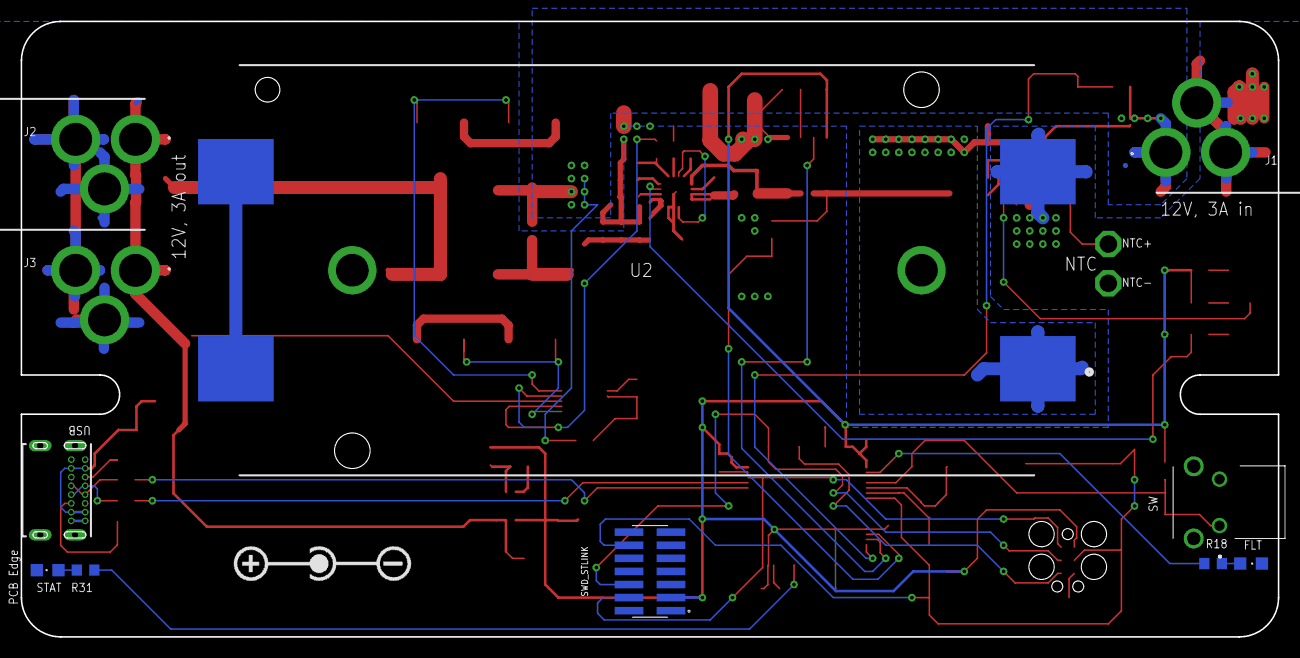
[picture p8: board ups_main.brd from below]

Board: 2 copper layers, 121.9 x 59.7 mm, 86 parts (11 on the bottom side), 60 nets.

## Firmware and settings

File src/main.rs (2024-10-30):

//#![deny(unsafe_code)]
#![no_main]
#![no_std]
// For allocator
#![feature(lang_items)]
#![feature(alloc_error_handler)]

extern crate alloc;

use alloc::sync::Arc;
use micromath::F32Ext;

use cortex_m::asm;
use cortex_m_rt::exception;
use cortex_m_rt::{entry, ExceptionFrame};
use panic_halt as _;
use stm32f4xx_hal::otg_fs::{USB};
use stm32f4xx_hal::{
    pac::{self, Interrupt},
    gpio::{Edge},
    prelude::*,
};
use crate::devices::led::LED;
use crate::intrpt::{G_BUTTON, G_STATE};

use freertos_rust::*;
use core::alloc::Layout;
use core::borrow::BorrowMut;
use core::f32::consts::PI;
use crate::report::{HID_PD_PRESENTSTATUS, HID_PD_REMAININGCAPACITY, HID_PD_RUNTIMETOEMPTY, Report, Status};
use modular_bitfield_to_value::ToValue;
use stm32f4xx_hal::adc::config::{AdcConfig, Dma, SampleTime, Scan, Sequence};
use stm32f4xx_hal::adc::{Adc, Temperature};
use stm32f4xx_hal::dma::config::DmaConfig;
use stm32f4xx_hal::dma::{StreamsTuple, Transfer};
use stm32f4xx_hal::timer::Channel4;
use crate::adc::{read_current, read_v_bat, read_v_in, ADC_MEMORY, G_XFR};
use arrform::{arrform, ArrForm};

mod devices;
mod intrpt;
mod usb_hid;
mod report;
mod adc;
mod utils;
mod usb_serial;

#[global_allocator]
static GLOBAL: FreeRtosAllocator = FreeRtosAllocator;


use crate::usb_hid::{G_USB_HID, usb_hid_init, G_USB_DEVICE, G_USB_HID_MODE};
use crate::usb_serial::{usb_println, usb_serial_init};
use crate::utils::LEDState;

#[entry]
fn main() -> ! {
    let mut dp = pac::Peripherals::take().unwrap();

    let rcc = dp.RCC.constrain();

    let clocks = rcc
        .cfgr
        .use_hse(8.MHz())
        .sysclk(48.MHz())
        .hclk(48.MHz())
        .require_pll48clk()
        .pclk1(24.MHz())
        .pclk2(24.MHz())
        .freeze();

    let mut delay = dp.TIM1.delay_us(&clocks);
    delay.delay(100.millis());  // apparently required for USB to set up properly...

    // initialize ports
    let gpioa = dp.GPIOA.split();
    let gpiob = dp.GPIOB.split();
    let gpioc = dp.GPIOC.split();
    let gpioe = dp.GPIOE.split();
    let _gpiod = dp.GPIOD.split();

    // initialize dma
    let dma2 = StreamsTuple::new(dp.DMA2);

    // initialize leds
    let led_dim = Channel4::new(gpiob.pb1);

    let mut usb_led1 = LED::new(gpioc.pc13.into_push_pull_output());

    // initialize pwm timer 3
    let mut stat_led_pwm = dp
        .TIM3
        .pwm_hz(led_dim, 10000.Hz(), &clocks)
        .split();


    // initialize pins

    let mut adc_vbat = gpioa.pa0.into_analog();
    let mut adc_current = gpioa.pa1.into_analog();
    let mut adc_vin = gpioa.pa2.into_analog();

    let dma_config = DmaConfig::default()
        .transfer_complete_interrupt(true)
        .memory_increment(true)
        .double_buffer(false);

    let adc_config = AdcConfig::default()
        .dma(Dma::Continuous)
        .scan(Scan::Enabled);
    let mut adc = Adc::adc1(dp.ADC1, true, adc_config);

    adc.configure_channel(&Temperature, Sequence::One, SampleTime::Cycles_480);
    adc.configure_channel(&adc_vbat, Sequence::Two, SampleTime::Cycles_3);
    adc.configure_channel(&adc_vin, Sequence::Three, SampleTime::Cycles_3);
    adc.configure_channel(&adc_current, Sequence::Four, SampleTime::Cycles_3);
    adc.enable_temperature_and_vref();

    // let adc_buffer = cortex_m::singleton!(: [u16; 2] = [0; 2]).unwrap();
    let mut transfer = unsafe {
        Transfer::init_peripheral_to_memory(dma2.0, adc, &mut ADC_MEMORY, None, dma_config)
    };

    transfer.start(|adc| {
        adc.start_conversion();
    });
    cortex_m::interrupt::free(|cs| {
        G_XFR.borrow(cs).replace(Some(transfer));
    });

    // initialize switch
    let sw = gpioc.pc15.into_floating_input();
    // let mut syscfg = dp.SYSCFG.constrain();
    // sw.make_interrupt_source(&mut syscfg);
    // sw.trigger_on_edge(&mut dp.EXTI, Edge::Rising);
    // sw.enable_interrupt(&mut dp.EXTI);

    // initialize usb
    let usb = USB {
        usb_global: dp.OTG_FS_GLOBAL,
        usb_device: dp.OTG_FS_DEVICE,
        usb_pwrclk: dp.OTG_FS_PWRCLK,
        pin_dm: stm32f4xx_hal::gpio::alt::otg_fs::Dm::PA11(gpioa.pa11.into_alternate()),
        pin_dp: stm32f4xx_hal::gpio::alt::otg_fs::Dp::PA12(gpioa.pa12.into_alternate()),
        hclk: clocks.hclk(),
    };
    delay.delay(100.millis());

    let hid_mode = sw.is_high();
    cortex_m::interrupt::free(|cs| {
        *G_USB_HID_MODE.borrow(cs).borrow_mut() = hid_mode;
    });

    unsafe {
        if hid_mode {
            usb_hid_init(usb);
        } else {
            usb_serial_init(usb);
        }
        cortex_m::peripheral::NVIC::unmask(Interrupt::OTG_FS);
        // Enable the external interrupt in the NVIC by passing the button interrupt number
        // cortex_m::peripheral::NVIC::unmask(sw.interrupt());
    }

    // Now that button is configured, move button into global context
    // cortex_m::interrupt::free(|cs| {
    //     G_BUTTON.borrow(cs).replace(Some(sw));
    // });


    for i in 0..=3 {
        delay.delay(1000.millis());
        match i {
            0 => {
                stat_led_pwm.enable();
                stat_led_pwm.set_duty(8000)
            }
            1 => { usb_led1.on() }
            _ => {
                stat_led_pwm.disable();
                usb_led1.off();
            }
        }
    }

    let led_state = LEDState::SlowBreathing;
    let led_state_container =
        Arc::new(Mutex::new(led_state).expect("Failed to create led state guard mutex"));
    let led_state_container_main = led_state_container.clone();
    let led_state_container_led = led_state_container;


    for _ in 0..=4 {
        delay.delay(200.millis());
    }


    Task::new()
        .name("USB TASK")
        .stack_size(1024)
        .priority(TaskPriority(3))
        .start(move || {
            let mut current = 0.0;
            let mut vbat = 0.0;
            let mut vin = 0.0;
            let mut supply_present = false;
            let mut capacity = 0;
            let mut remaining_seconds = 0;

            let mut old_capacity = 100;
            let mut old_remaining_seconds = 1;

            let battery_capacity = 2.0 * 3.7 * 2100.0; // Wh

            let mut remaining_capacity_report = Report::new_u8(HID_PD_REMAININGCAPACITY, 50);
            let mut runtime_empty_report = Report::new_u16(HID_PD_RUNTIMETOEMPTY, 1);
            let mut status = Status::new();
            let mut old_status = Status::new();
            status.set_charging(1);
            status.set_ac_present(1);
            status.set_battery_present(0);

            let mut led_state = LEDState::SlowBreathing;

            let mut status_report = Report::new_u16(HID_PD_PRESENTSTATUS, status.to_u16_le().unwrap());
            loop {
                current = read_current();
                vbat = read_v_bat();
                vin = read_v_in();
                supply_present = vin > 10.0;

                // if vbat < 4.0 && supply_present {
                //     status.set_charging(1);
                //     status_report.update_u16_value(status.to_u16_le().unwrap());
                // } else if !supply_present {
                //     status.set_charging(0);
                //     status.set_discharging(1);
                //     status_report.update_u16_value(status.to_u16_le().unwrap());
                // }

                if supply_present {
                    status.set_ac_present(1);
                    status.set_charging(1);
                    status.set_battery_present(0);
                    status_report.update_u16_value(status.to_u16_le().unwrap());
                    led_state = LEDState::SlowBreathing;
                } else {
                    status.set_ac_present(0);
                    status.set_charging(0);
                    status.set_battery_present(1);
                    status_report.update_u16_value(status.to_u16_le().unwrap());
                    led_state = LEDState::FastBreathing;
                }

                if vbat < 3.5 {
                    status.set_remaining_time_limit_expired(1);
                    status.set_shutdown_requested(1);
                    status_report.update_u16_value(status.to_u16_le().unwrap());
                }

                if vbat < 3.2 {
                    status.set_shutdown_imminent(1);
                    status_report.update_u16_value(status.to_u16_le().unwrap());
                }

                if status.to_u16_le().unwrap() != old_status.to_u16_le().unwrap() {
                    if hid_mode {
                        cortex_m::interrupt::free(|cs| {
                            if let Some(hid) = G_USB_HID.borrow(cs).borrow_mut().as_mut() {
                                hid.send_report(&status_report);
                            };
                        });
                    }
                    old_status = status;
                }

                capacity = (100.0 / (4.15 - 3.3) * (vbat - 3.3)) as u8;
                remaining_seconds = (battery_capacity / vbat / current) as u16;

                if capacity != old_capacity {
                    remaining_capacity_report = Report::new_u8(HID_PD_REMAININGCAPACITY, capacity);
                    old_capacity = capacity;
                    if hid_mode {
                        cortex_m::interrupt::free(|cs| {
                            if let Some(hid) = G_USB_HID.borrow(cs).borrow_mut().as_mut() {
                                hid.send_report(&remaining_capacity_report);
                            };
                        });
                    }
                }
                if remaining_seconds != old_remaining_seconds {
                    runtime_empty_report = Report::new_u16(HID_PD_RUNTIMETOEMPTY, remaining_seconds);
                    old_remaining_seconds = remaining_seconds;
                    if hid_mode {
                        cortex_m::interrupt::free(|cs| {
                            if let Some(hid) = G_USB_HID.borrow(cs).borrow_mut().as_mut() {
                                hid.send_report(&runtime_empty_report);
                            };
                        });
                    }
                }

                if hid_mode {
                    cortex_m::interrupt::free(|cs| {
                        if let Some(hid) = G_USB_HID.borrow(cs).borrow_mut().as_mut() {
                            hid.send_report(&status_report);
                            usb_led1.toggle();
                        };
                    });
                } else {
                    usb_println(arrform!(128, "v_bat: {}, v_in: {}, current: {}, remaining seconds: {}",vbat, vin, current, remaining_seconds ).as_str());
                }

                if let Ok(mut guard) = led_state_container_main.lock(Duration::ms(1)) {
                    *guard = led_state.clone();
                }

                CurrentTask::delay(Duration::ms(500));
            }
        }).unwrap();

    Task::new()
        .name("BLINK TASK")
        .stack_size(256)
        .priority(TaskPriority(2))
        .start(move || {
            let max_duty = stat_led_pwm.get_max_duty();
            let mut count = 0;
            let mut led_state = LEDState::SlowBreathing;
            loop {
                if let Ok(guard) = led_state_container_led.lock(Duration::ms(1)) {
                    led_state = guard.clone();
                }
                stat_led_pwm.enable();
                let val = max_duty
                    - (max_duty as f32 * (count as f32 / 1024.0 * PI).sin()) as u16; // LED1
                stat_led_pwm.set_duty(val);
                match led_state {
                    LEDState::FastBreathing => {
                        count += 20;
                        CurrentTask::delay(Duration::ms(5));
                    }
                    LEDState::SlowBreathing => {
                        count += 10;
                        CurrentTask::delay(Duration::ms(10));
                    }
                }
            }
        }).unwrap();

    FreeRtosUtils::start_scheduler();
}


#[exception]
#[allow(non_snake_case)]
unsafe fn DefaultHandler(_irqn: i16) {
    // custom default handler
    // irqn is negative for Cortex-M exceptions
    // irqn is positive for device specific (line IRQ)
    // panic!("Exception: {}", irqn);
}

#[exception]
#[allow(non_snake_case)]
unsafe fn HardFault(_ef: &ExceptionFrame) -> ! {
    loop {}
}

// define what happens in an Out Of Memory (OOM) condition
#[alloc_error_handler]
fn alloc_error(_layout: Layout) -> ! {
    asm::bkpt();
    loop {}
}

#[no_mangle]
#[allow(non_snake_case, unused_variables)]
fn vApplicationStackOverflowHook(pxTask: FreeRtosTaskHandle, pcTaskName: FreeRtosCharPtr) {
    asm::bkpt();
}

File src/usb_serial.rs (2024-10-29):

use core::cell::RefCell;

// use arrform::{arrform, ArrForm};
use cortex_m::interrupt::Mutex;
use stm32f4xx_hal::otg_fs::{UsbBus, USB};
use stm32f4xx_hal::pac::interrupt;
use usb_device::bus::UsbBusAllocator;
use usb_device::prelude::*;
use usbd_serial::SerialPort;

// Make USB serial device globally available
pub static G_USB_SERIAL: Mutex<RefCell<Option<SerialPort<UsbBus<USB>>>>> =
    Mutex::new(RefCell::new(None));

// Make USB device globally available
pub static G_USB_DEVICE: Mutex<RefCell<Option<UsbDevice<UsbBus<USB>>>>> =
    Mutex::new(RefCell::new(None));

pub static mut EP_MEMORY: [u32; 1024] = [0; 1024];
static mut USB_BUS: Option<UsbBusAllocator<stm32f4xx_hal::otg_fs::UsbBusType>> = None;

#[allow(dead_code)]
pub unsafe fn usb_serial_init(usb: USB) {
    USB_BUS = Some(stm32f4xx_hal::otg_fs::UsbBusType::new(usb, &mut EP_MEMORY));
    let usb_bus = USB_BUS.as_ref().unwrap();
    let serial_port = SerialPort::new(&usb_bus);
    let usb_dev = UsbDeviceBuilder::new(&usb_bus, UsbVidPid(0x03f0, 0x1f06))
        .device_class(usbd_serial::USB_CLASS_CDC)
        .strings(&[StringDescriptors::default()
            .manufacturer("hacknus")
            .product("UPS")
            .serial_number("UPS10")])
        .unwrap()
        .build();

    cortex_m::interrupt::free(|cs| {
        *G_USB_SERIAL.borrow(cs).borrow_mut() = Some(serial_port);
        *G_USB_DEVICE.borrow(cs).borrow_mut() = Some(usb_dev);
    });
}

#[allow(dead_code)]
pub fn usb_read(message: &mut [u8; 1024]) -> bool {
    cortex_m::interrupt::free(|cs| {
        *message = [0; 1024];
        return match G_USB_SERIAL.borrow(cs).borrow_mut().as_mut() {
            None => false,
            Some(serial) => match serial.read(message) {
                Ok(a) => {
                    if a < 1024 {
                        true
                    } else {
                        false
                    }
                }
                Err(_err) => {
                    // usb_println(arrform!(128, "Serial read Error: {:?}", err).as_str());
                    // let _ = serial.flush();
                    false
                }
            },
        };
    })
}

#[allow(dead_code)]
pub fn usb_println(string: &str) {
    cortex_m::interrupt::free(|cs| match G_USB_SERIAL.borrow(cs).borrow_mut().as_mut() {
        None => {}
        Some(serial) => {
            let string_bytes = string.as_bytes();
            let mut index = 0;
            let length = 32;
            loop {
                if string_bytes.len() > index + length {
                    let bytes_to_send = &string_bytes[index..index + length];
                    serial.write(bytes_to_send).unwrap_or(0);
                    serial.flush().unwrap_or(());
                } else {
                    let bytes_to_send = &string_bytes[index..];
                    serial.write(bytes_to_send).unwrap_or(0);
                    serial.flush().unwrap_or(());
                    break;
                }
                index += length;
            }
            serial.write(b"\r\n").unwrap_or(0);
            serial.flush().unwrap_or(());
        }
    })
}

#[allow(dead_code)]
pub fn usb_print(string: &str) {
    cortex_m::interrupt::free(|cs| match G_USB_SERIAL.borrow(cs).borrow_mut().as_mut() {
        None => {}
        Some(serial) => {
            serial.write(string.as_bytes()).unwrap_or(0);
            serial.flush().unwrap_or(());
        }
    })
}

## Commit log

2024-08-12 change vid/pid and descriptor
2024-08-12 testing battery level reporting
2024-08-12 capacity to u8
2024-08-13 reporting in usb interrupt
2024-09-27 add hardware files
    [ups_main.brd, ups_main.sch, ups_main_bom.csv]
2024-09-30 slow sine for LED implemented
2024-10-01 update schem
    [ups_main.brd, ups_main.sch, ups_main_bom.csv]
2024-10-01 add BMS note
    [ups_main_bom.csv]
2024-10-26 fix errors in schem/layout
    [ups_main.brd, ups_main.sch, ups_main_bom.csv]
2024-10-27 fix pgood led
    [ups_main.brd, ups_main.sch]
2024-10-28 change led blink speed when power supply is disconnected
2024-10-28 fix adc
2024-10-28 fix voltage reading
2024-10-28 switch battery and ac present flags
2024-10-29 include usb interrupt for serial
2024-10-30 no charging might trigger shutdown
2026-04-29 Update README with caution about PCB design error
    Added caution note about PCB design error.
2026-10-30 add new USB re-mounting and rev 2 docs
2026-10-30 add case for 3D printing

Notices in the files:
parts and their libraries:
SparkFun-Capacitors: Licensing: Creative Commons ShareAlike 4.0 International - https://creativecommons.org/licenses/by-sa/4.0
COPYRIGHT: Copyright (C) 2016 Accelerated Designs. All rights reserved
